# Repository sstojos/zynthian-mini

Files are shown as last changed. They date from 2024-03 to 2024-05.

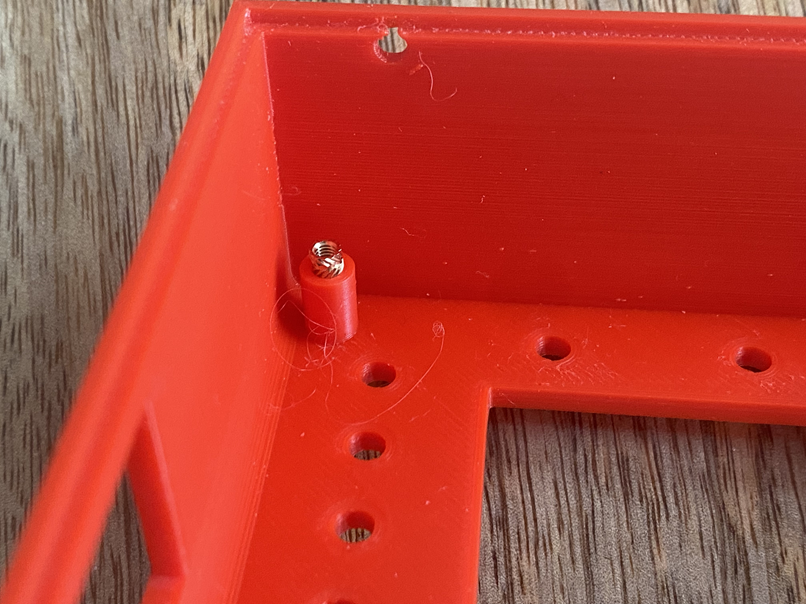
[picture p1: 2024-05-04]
resources/assembly-1.png

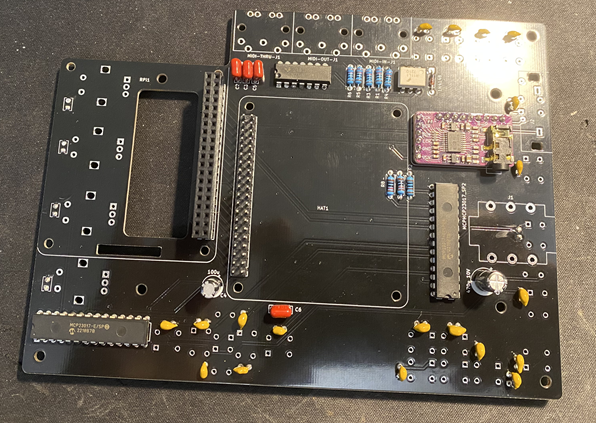
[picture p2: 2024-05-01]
resources/soldering-step-6.png

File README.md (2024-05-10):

THIS IS AN OLD reposiotry OF ZYNTHIAN MINI !!!

Zyntian MINI is not any more maintained here.

Zynthian MINI is now merged to zynthian-hw repository. You can find latest verison of zynthian mini inside [forked repository of zynthian-hw](https://github.com/sstojos/zynthian-hw) inside MINI_V2 folder.

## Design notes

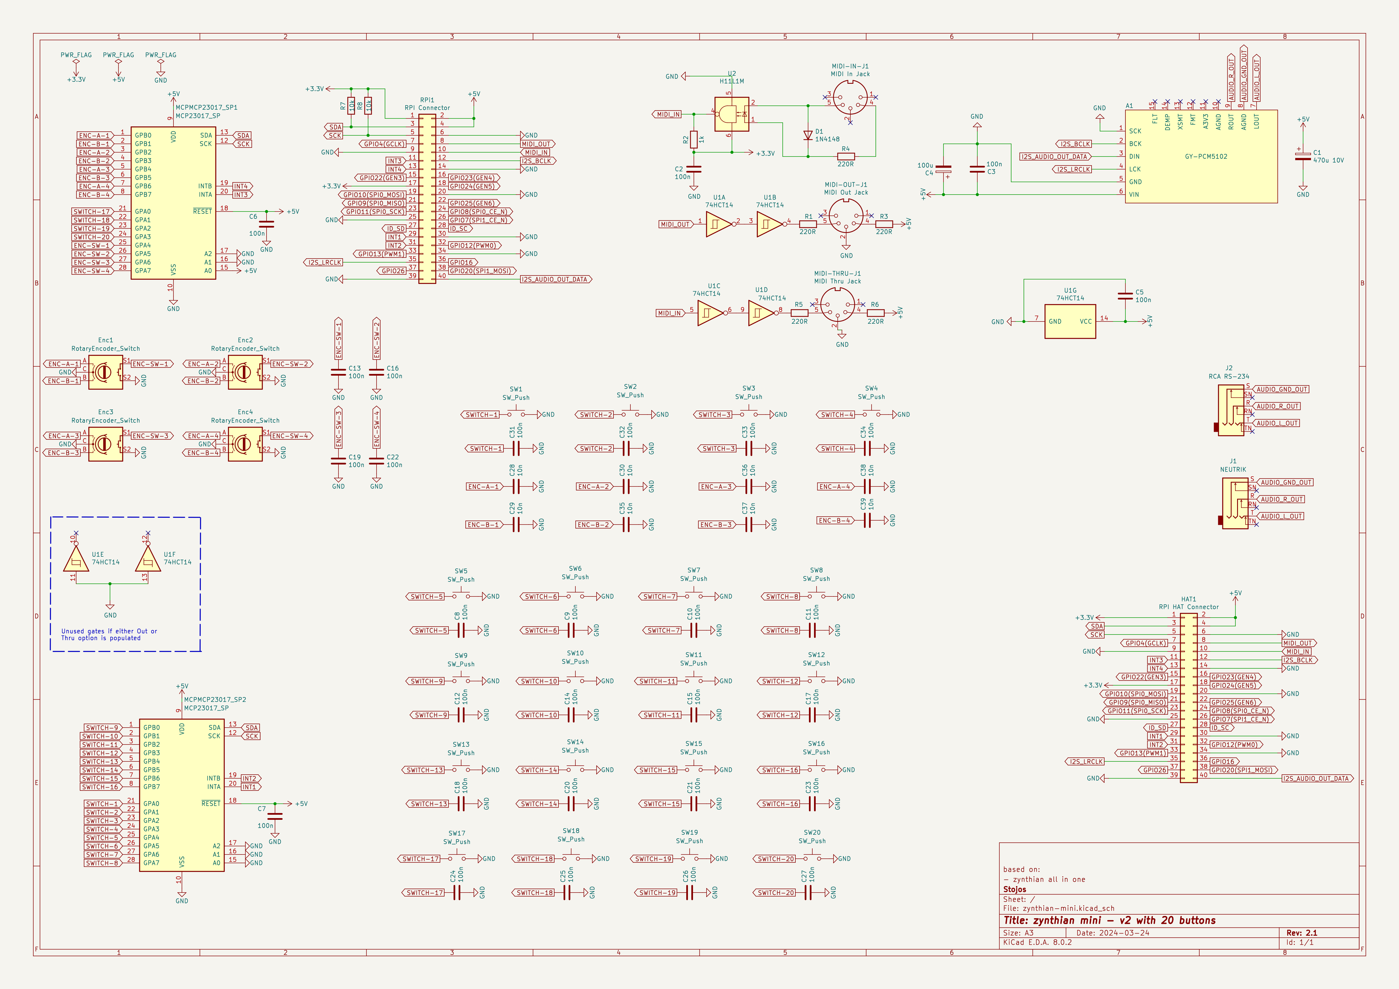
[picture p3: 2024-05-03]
resources/schematics.png

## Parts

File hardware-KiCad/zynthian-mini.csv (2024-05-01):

Id | Designator | Footprint | Quantity | Designation | Supplier and ref
1 | RPi1 | raspberry pi 4 HAT | 1 | RPI Connector
2 | C1 | CP_Radial_D8.0mm_P3.50mm | 1 | 470u 10V
3 | C2,C3,C5,C6,C7 | C_Rect_L7.0mm_W2.0mm_P5.00mm | 5 | 100n
4 | C4 | CP_Radial_D6.3mm_P2.50mm | 1 | 100u
5 | D1 | D_DO-35_SOD27_P7.62mm_Horizontal | 1 | 1N4148
6 | MIDI-OUT-J1 | MultiDIN5 | 1 | MIDI Out Jack
7 | MIDI-IN-J1 | MultiDIN5 | 1 | MIDI In Jack
8 | R1,R3,R5,R4,R6 | R_Axial_DIN0207_L6.3mm_D2.5mm_P7.62mm_Horizontal | 5 | 220R
9 | R2 | R_Axial_DIN0207_L6.3mm_D2.5mm_P7.62mm_Horizontal | 1 | 1k
10 | U2 | DIP-6_W7.62mm | 1 | H11L1M
11 | U1 | DIP-14_W7.62mm | 1 | 74HCT14
12 | A1 | GY-PCM5102 | 1 | GY-PCM5102
13 | C30,C29,C35,C37,C38,C28,C39,C36 | C_Rect_L4.0mm_W2.5mm_P2.50mm | 8 | 10n
14 | J2 | RCA RS-234 | 1 | RCA RS-234
15 | HAT1 | raspberry pi 4 | 1 | RPI HAT Connector
16 | R8,R7 | R_Axial_DIN0207_L6.3mm_D2.5mm_P7.62mm_Horizontal | 2 | 10k
17 | MCPMCP23017_SP2,MCPMCP23017_SP1 | DIP-28_W7.62mm | 2 | MCP23017_SP
18 | C22,C16,C19,C13,C23,C20,C9,C26,C27,C32,C8,C18,C21,C34,C33,C17,C25,C11,C24,C31,C12,C15,C10,C14 | C_Rect_L4.0mm_W2.5mm_P2.50mm | 24 | 100n
19 | MIDI-THRU-J1 | MultiDIN5 | 1 | MIDI Thru Jack
20 | screen | aliexpress 5 inch screen | 1 | aliexpress 5 inch screen
21 | J1 | Jack_6.35mm_Neutrik_NMJ6HFD2_Horizontal | 1 | NEUTRIK
22 | SW14,SW9,SW16,SW20,SW6,SW10,SW8,SW2,SW17,SW4,SW12,SW19,SW5,SW1,SW13,SW18,SW15,SW7,SW11,SW3 | push-button | 20 | SW_Push
23 | Enc2,Enc4,Enc1,Enc3 | RotaryEncoder_Alps_EC12E-Switch_Vertical_H20mm | 4 | RotaryEncoder_Switch
24 | G*** | Zynthian Logo Mask | 1 | MINI v2

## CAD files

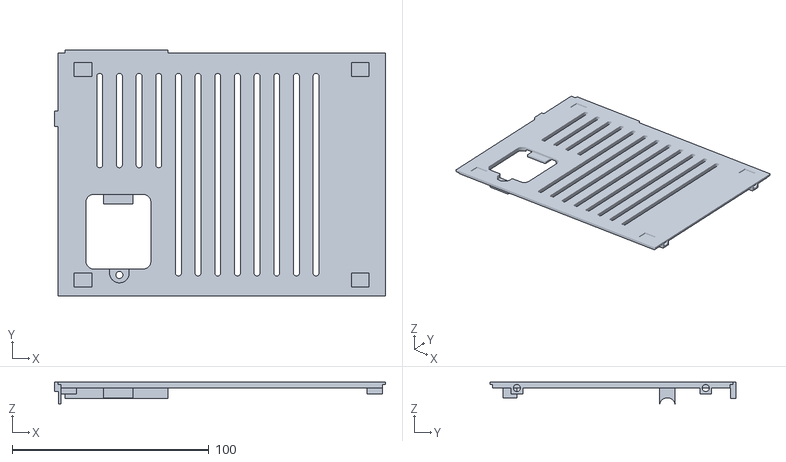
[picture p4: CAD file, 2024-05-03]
CAD/bottom.stl
168.3 x 125.3 x 11.1

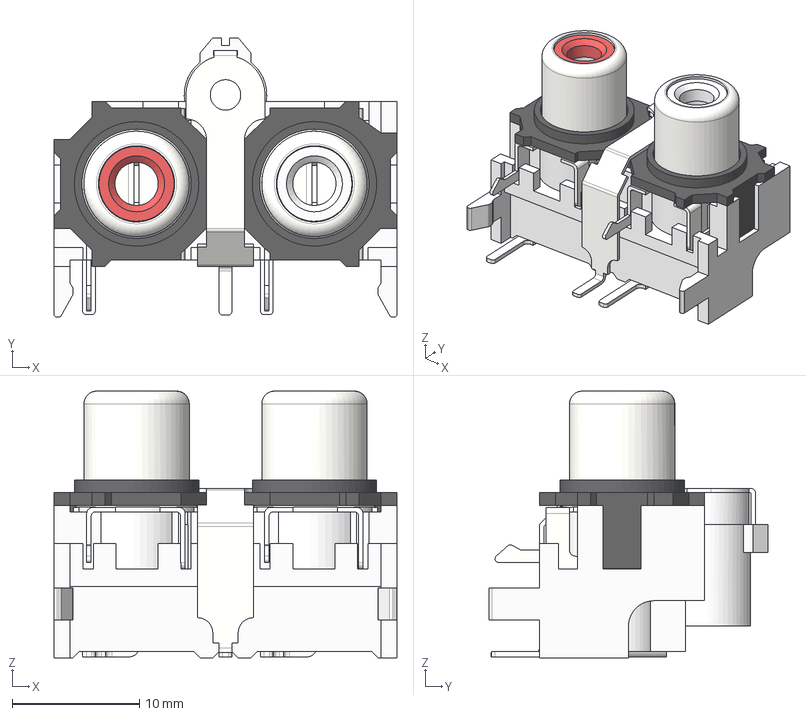
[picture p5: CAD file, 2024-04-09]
hardware-KiCad/RS-234.stp
27.0 x 22.0 x 21.0 mm

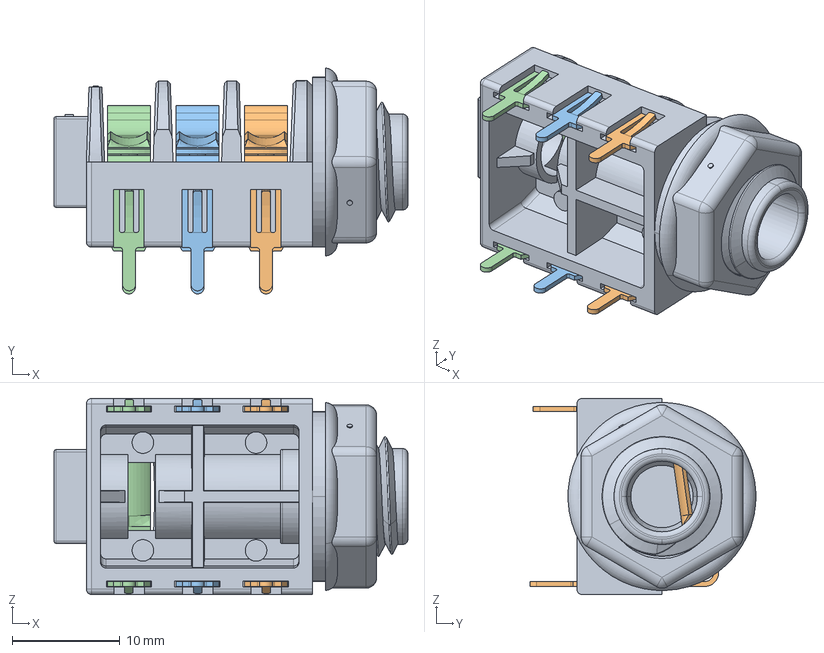
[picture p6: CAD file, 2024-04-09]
hardware-KiCad/nmj6hfd2.stp
32.9 x 21.0 x 18.2 mm

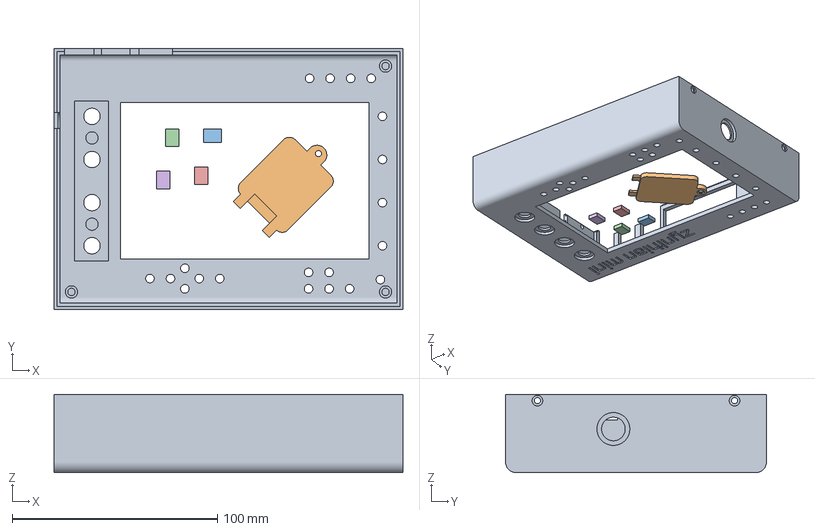
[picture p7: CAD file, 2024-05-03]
CAD/orca-slicer-project-01.3mf
170.0 x 127.0 x 38.0 mm
top.stl
sd-card-door.stl
leg.stl x 4

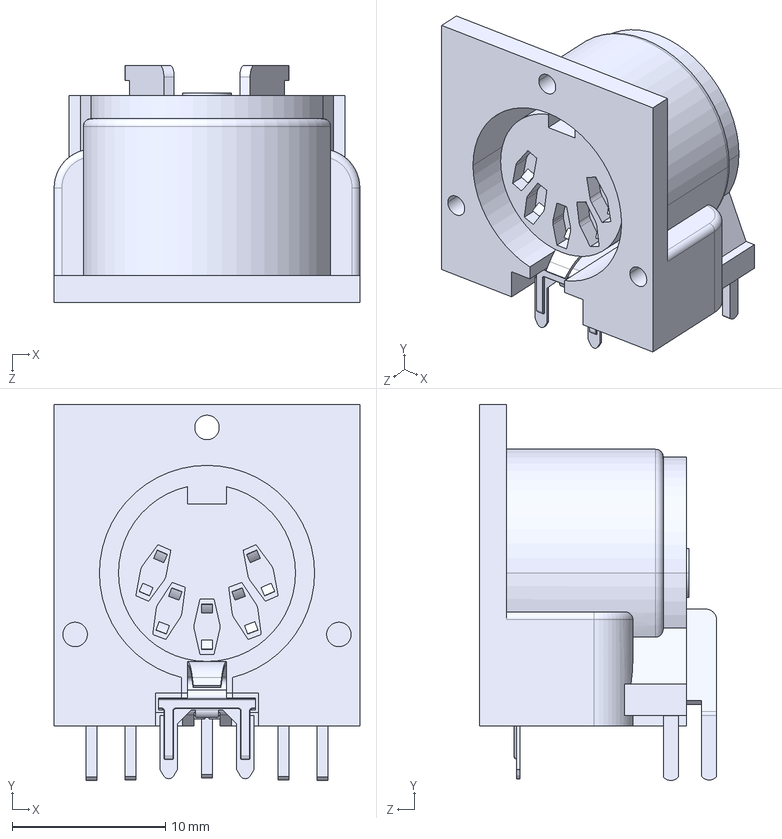
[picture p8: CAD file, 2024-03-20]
hardware-KiCad/midi-connector.step
20.0 x 24.5 x 15.5 mm

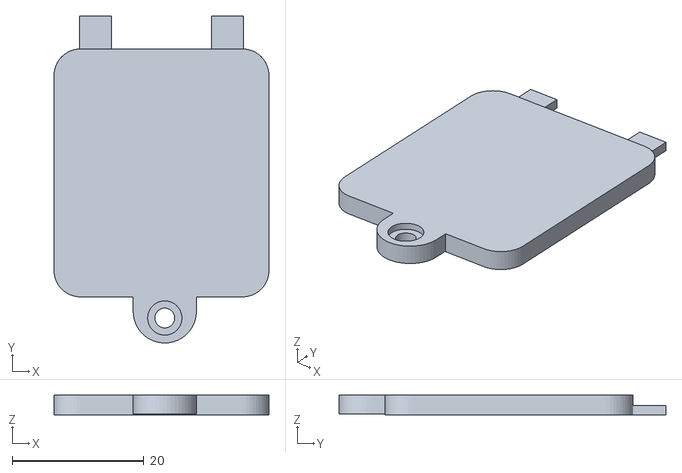
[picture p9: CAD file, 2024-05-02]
CAD/sd-card-door.stl
32.6 x 49.6 x 3.00

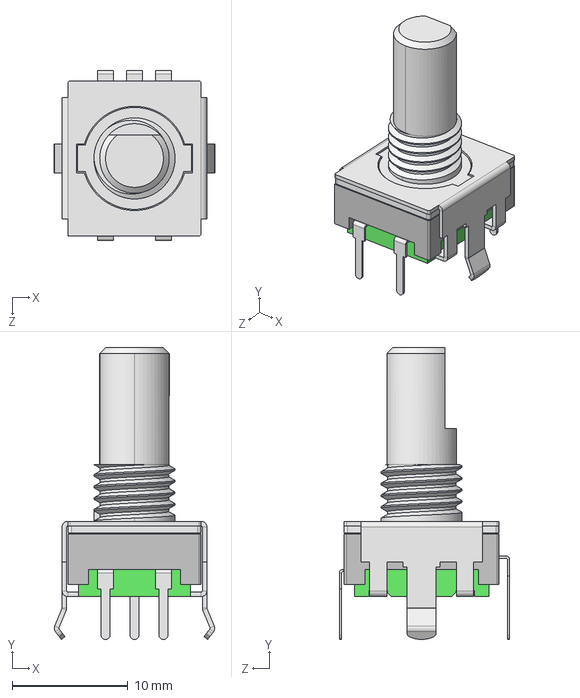
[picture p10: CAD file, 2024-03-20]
hardware-KiCad/rotary-encoder.step
13.9 x 25.2 x 14.7 mm

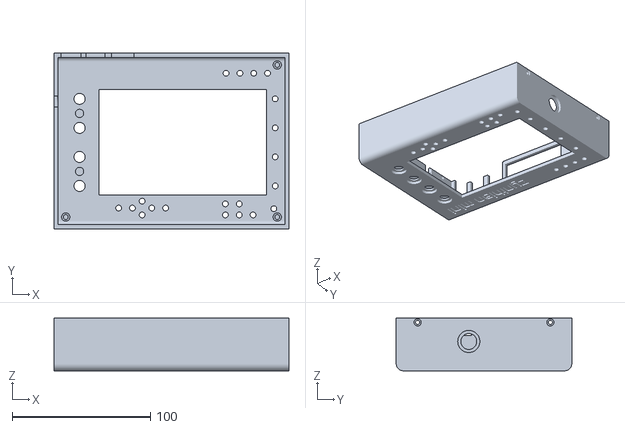
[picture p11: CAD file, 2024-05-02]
CAD/top.stl
170.0 x 127.0 x 38.0

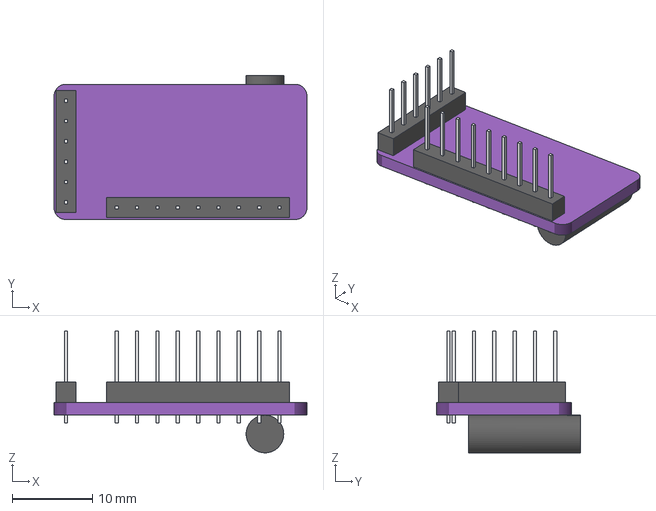
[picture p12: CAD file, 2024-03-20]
hardware-KiCad/PCM5102-I2S.step
31.6 x 18.0 x 15.2 mm

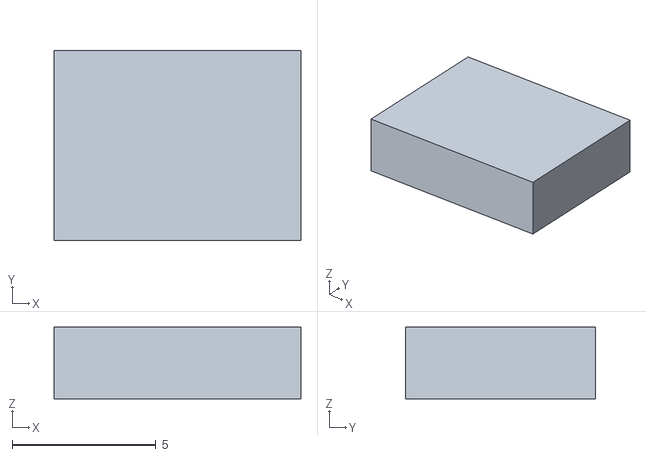
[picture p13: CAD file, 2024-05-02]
CAD/leg.stl
8.60 x 6.60 x 2.50

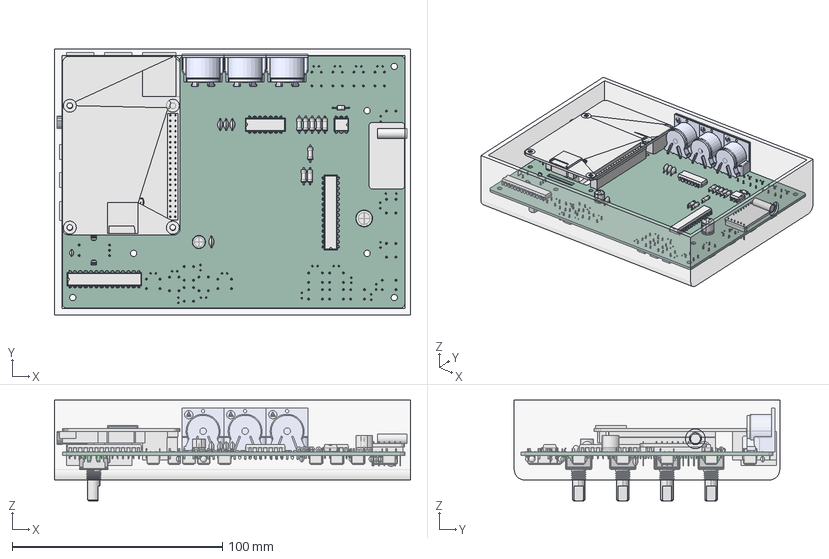
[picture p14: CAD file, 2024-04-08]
CAD/case-freecad.FCStd
169.4 x 126.4 x 48.0 mm
Top Case
Raspberry Pi 4 B
Raspberry Pi 4 B001
Raspberry Pi 4 B002
Raspberry Pi 4 B003
Raspberry Pi 4 B004
Raspberry Pi 4 B005
Raspberry Pi 4 B006
Raspberry Pi 4 B007
Raspberry Pi 4 B008
Raspberry Pi 4 B009
Raspberry Pi 4 B010
Raspberry Pi 4 B011
Raspberry Pi 4 B012
Raspberry Pi 4 B013
Raspberry Pi 4 B014
Raspberry Pi 4 B015
Raspberry Pi 4 B016
Raspberry Pi 4 B017
Raspberry Pi 4 B018
Raspberry Pi 4 B019
Raspberry Pi 4 B020
PinSocket_2x20_P254mm_Vertical
CP_Radial_D80mm_P350mm
C_Disc_D50mm_W25mm_P500mm
C_Disc_D50mm_W25mm_P500mm001
CP_Radial_D63mm_P250mm
C_Disc_D50mm_W25mm_P500mm002
D_DO-35_SOD27_P7.62mm_Horizontal
D_DO-35_SOD27_P7.62mm_Horizontal001
57PC5F
57PC5F001
R_Axial_DIN0207_L63mm_D25mm_P762mm_Horizontal
R_Axial_DIN0207_L63mm_D25mm_P762mm_Horizontal001
R_Axial_DIN0207_L63mm_D25mm_P762mm_Horizontal002
R_Axial_DIN0207_L63mm_D25mm_P762mm_Horizontal003
DIP-6_W7.62mm
DIP-14_W7.62mm
R_Axial_DIN0207_L63mm_D25mm_P762mm_Horizontal004
R_Axial_DIN0207_L63mm_D25mm_P762mm_Horizontal005
DIP-28_W7.62mm
C_Disc_D30mm_W20mm_P250mm
C_Disc_D30mm_W20mm_P250mm001
R_Axial_DIN0207_L63mm_D25mm_P762mm_Horizontal006
R_Axial_DIN0207_L63mm_D25mm_P762mm_Horizontal007
57PC5F002
DIP-28_W7.62mm002
C_Disc_D50mm_W25mm_P500mm003
C_Disc_D30mm_W20mm_P250mm002
C_Disc_D30mm_W20mm_P250mm003
SW_PUSH_6mm
C_Disc_D30mm_W20mm_P250mm004
C_Disc_D50mm_W25mm_P500mm004
C_Disc_D30mm_W20mm_P250mm005
SW_PUSH_6mm002
C_Disc_D30mm_W20mm_P250mm006
C_Disc_D30mm_W20mm_P250mm007
PEC11R-4215F-S0024
PEC11R-4215F-S0025
PEC11R-4215F-S0026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

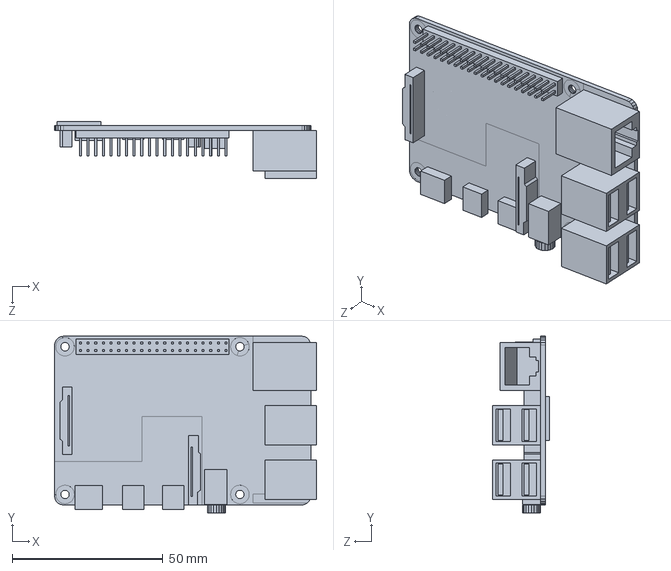
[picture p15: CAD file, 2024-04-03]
CAD/Raspberry_Pi_4_B.STEP
86.9 x 58.6 x 19.0 mm

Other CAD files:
CAD/orca-slicer-project-02.3mf

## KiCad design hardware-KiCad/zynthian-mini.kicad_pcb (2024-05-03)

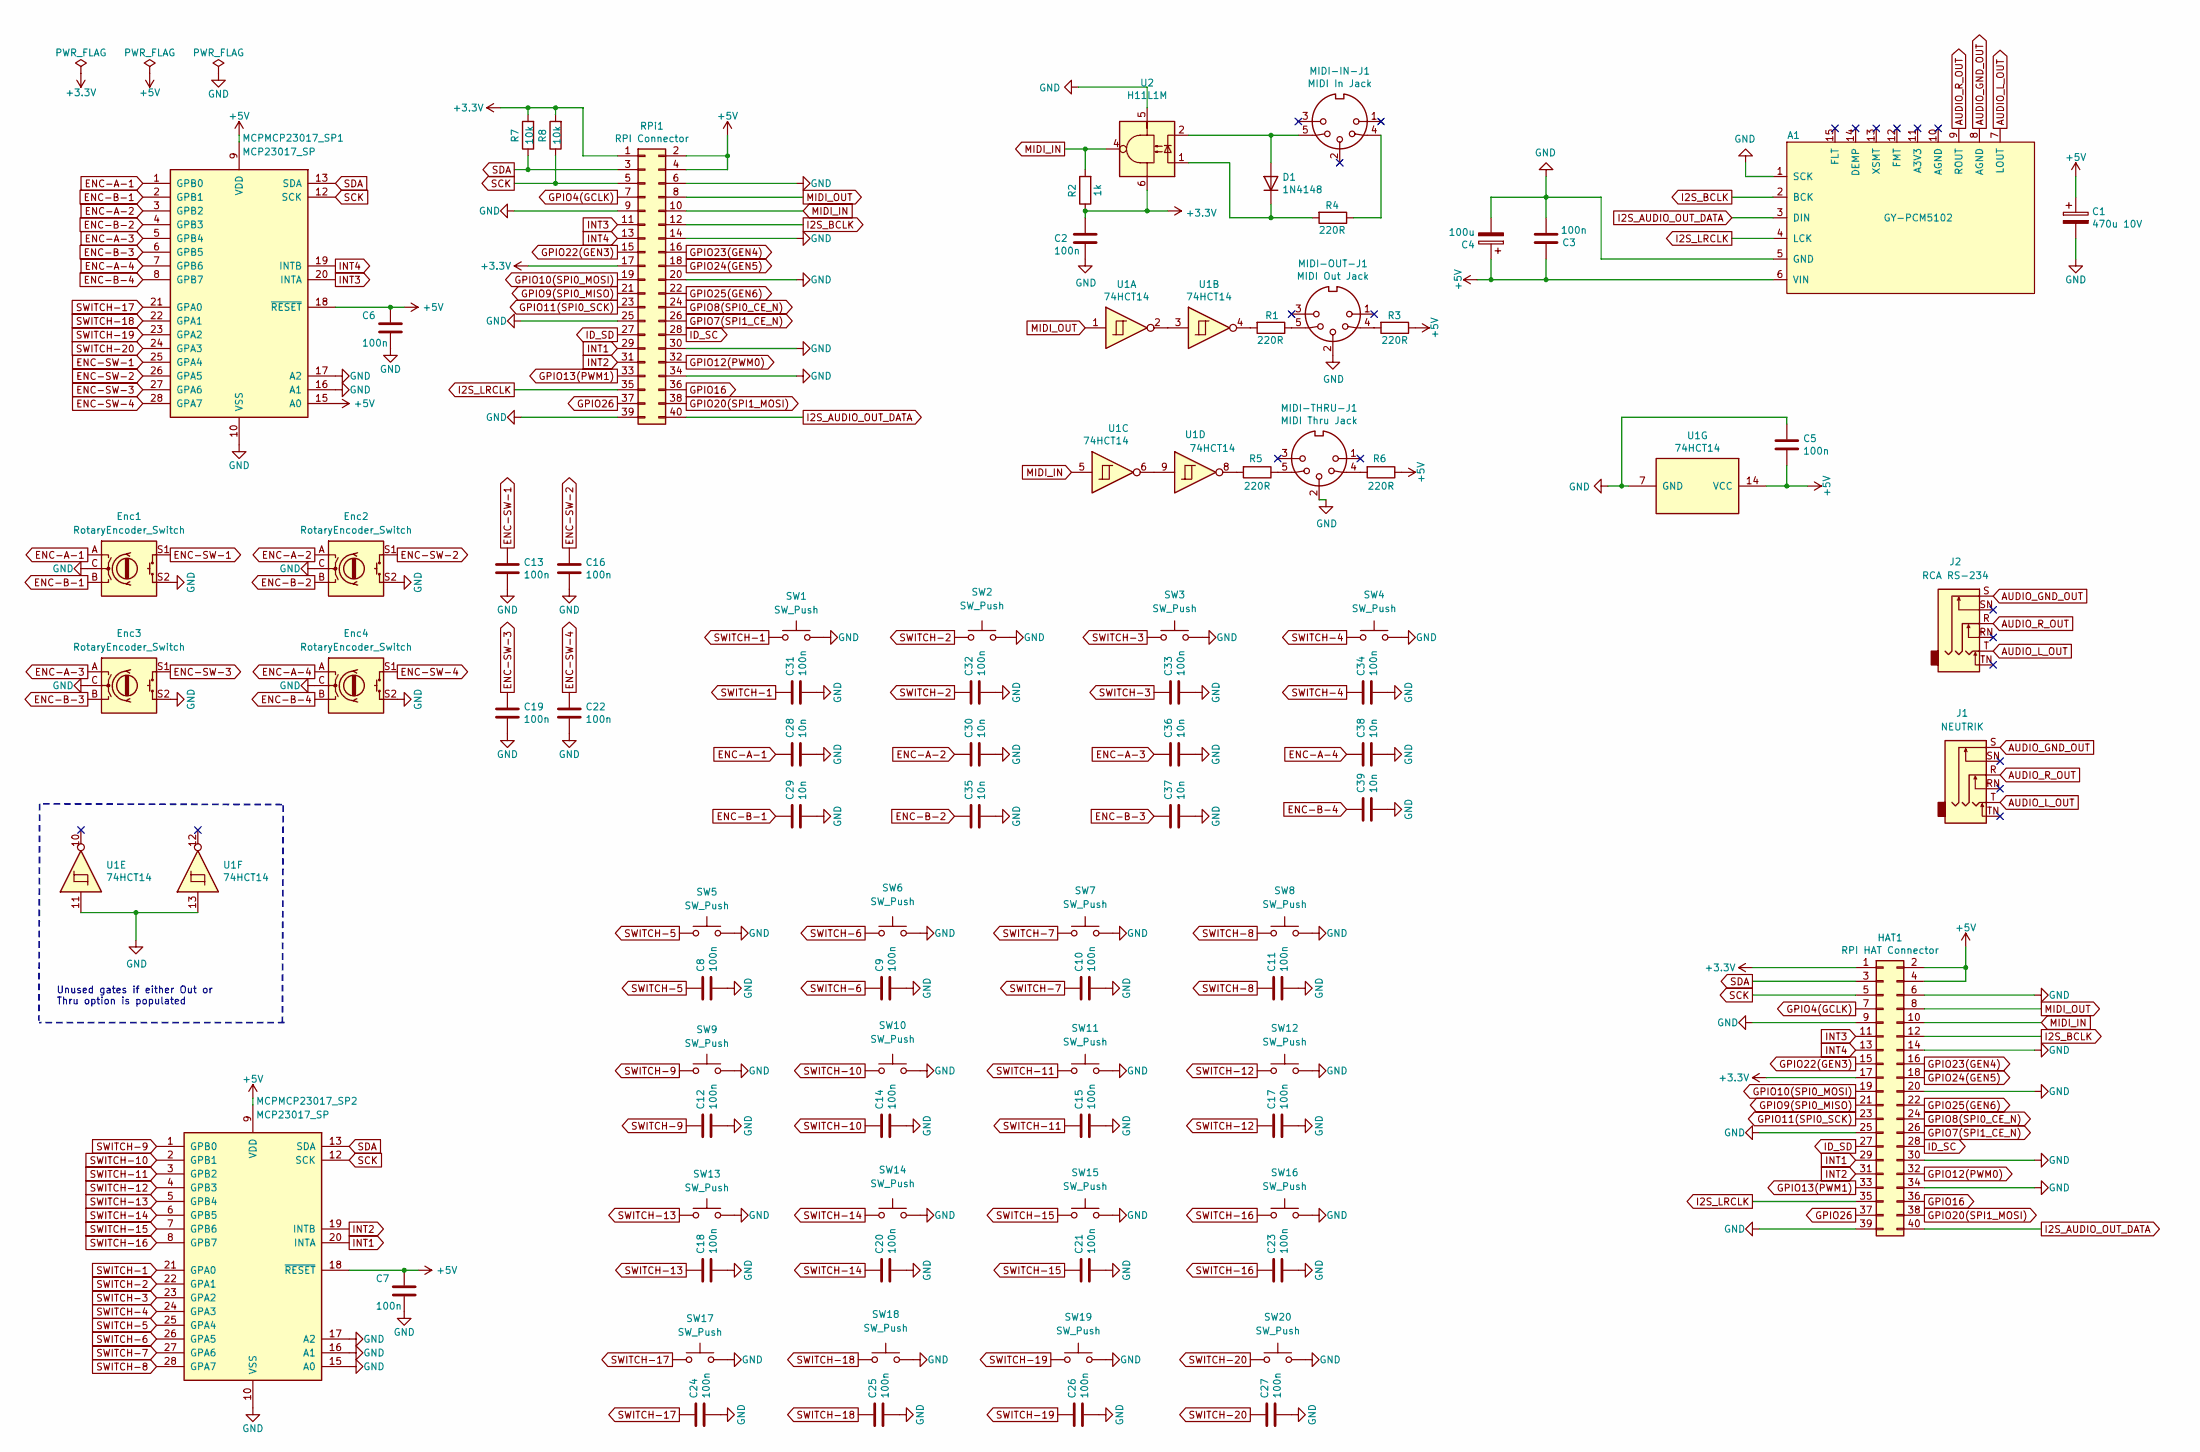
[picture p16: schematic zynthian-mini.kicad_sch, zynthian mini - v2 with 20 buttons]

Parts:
A1: GY-PCM5102
C1: 470u 10V; CP_Radial_D8.0mm_P3.50mm
C2, C3, C5, C6, C7: 100n; C_Rect_L7.0mm_W2.0mm_P5.00mm
C4: 100u; CP_Radial_D6.3mm_P2.50mm
C8, C9, C10, C11, C12, C13, C14, C15, C16, C17, C18, C19, C20, C21, C22, C23, C24, C25, C26, C27, C31, C32, C33, C34: 100n; C_Rect_L4.0mm_W2.5mm_P2.50mm
C28, C29, C30, C35, C36, C37, C38, C39: 10n; C_Rect_L4.0mm_W2.5mm_P2.50mm
D1: 1N4148; D_DO-35_SOD27_P7.62mm_Horizontal
Enc1, Enc2, Enc3, Enc4: RotaryEncoder_Switch; RotaryEncoder_Alps_EC12E-Switch_Vertical_H20mm
HAT1: RPI HAT Connector; raspberry pi 4
J1: NEUTRIK; Jack_6.35mm_Neutrik_NMJ6HFD2_Horizontal
J2: RCA RS-234
MCPMCP23017_SP1, MCPMCP23017_SP2: MCP23017_SP; DIP-28_W7.62mm
MIDI-IN-J1: MIDI In Jack; MultiDIN5
MIDI-OUT-J1: MIDI Out Jack; MultiDIN5
MIDI-THRU-J1: MIDI Thru Jack; MultiDIN5
R1, R3, R4, R5, R6: 220R; R_Axial_DIN0207_L6.3mm_D2.5mm_P7.62mm_Horizontal
R2: 1k; R_Axial_DIN0207_L6.3mm_D2.5mm_P7.62mm_Horizontal
R7, R8: 10k; R_Axial_DIN0207_L6.3mm_D2.5mm_P7.62mm_Horizontal
RPi1: RPI Connector; raspberry pi 4 HAT
SW1, SW2, SW3, SW4, SW5, SW6, SW7, SW8, SW9, SW10, SW11, SW12, SW13, SW14, SW15, SW16, SW17, SW18, SW19, SW20: SW_Push; push-button
U1: 74HCT14; DIP-14_W7.62mm
U2: H11L1M; DIP-6_W7.62mm

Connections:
AUDIO_GND_OUT: A1.8 (AGND), J1.S, J2.S
AUDIO_L_OUT: A1.7 (LOUT), J1.T, J2.T
AUDIO_R_OUT: A1.9 (ROUT), J1.R, J2.R
ENC-A-1: C28.1, Enc1.A, MCPMCP23017_SP1.1 (GPB0)
ENC-A-2: C30.1, Enc2.A, MCPMCP23017_SP1.3 (GPB2)
ENC-A-3: C36.1, Enc3.A, MCPMCP23017_SP1.5 (GPB4)
ENC-A-4: C38.1, Enc4.A, MCPMCP23017_SP1.7 (GPB6)
ENC-B-1: C29.1, Enc1.B, MCPMCP23017_SP1.2 (GPB1)
ENC-B-2: C35.1, Enc2.B, MCPMCP23017_SP1.4 (GPB3)
ENC-B-3: C37.1, Enc3.B, MCPMCP23017_SP1.6 (GPB5)
ENC-B-4: C39.1, Enc4.B, MCPMCP23017_SP1.8 (GPB7)
ENC-SW-1: C13.1, Enc1.S1, MCPMCP23017_SP1.25 (GPA4)
ENC-SW-2: C16.1, Enc2.S1, MCPMCP23017_SP1.26 (GPA5)
ENC-SW-3: C19.1, Enc3.S1, MCPMCP23017_SP1.27 (GPA6)
ENC-SW-4: C22.1, Enc4.S1, MCPMCP23017_SP1.28 (GPA7)
GPIO4(GCLK): HAT1.7, RPi1.7
GPIO7(SPI1_CE_N): HAT1.26, RPi1.26
GPIO8(SPI0_CE_N): HAT1.24, RPi1.24
GPIO9(SPI0_MISO): HAT1.21, RPi1.21
GPIO10(SPI0_MOSI): HAT1.19, RPi1.19
GPIO11(SPI0_SCK): HAT1.23, RPi1.23
GPIO12(PWM0): HAT1.32, RPi1.32
GPIO13(PWM1): HAT1.33, RPi1.33
GPIO16: HAT1.36, RPi1.36
GPIO20(SPI1_MOSI): HAT1.38, RPi1.38
GPIO22(GEN3): HAT1.15, RPi1.15
GPIO23(GEN4): HAT1.16, RPi1.16
GPIO24(GEN5): HAT1.18, RPi1.18
GPIO25(GEN6): HAT1.22, RPi1.22
GPIO26: HAT1.37, RPi1.37
I2S_AUDIO_OUT_DATA: A1.3 (DIN), HAT1.40, RPi1.40
I2S_BCLK: A1.2 (BCK), HAT1.12, RPi1.12
I2S_LRCLK: A1.4 (LCK), HAT1.35, RPi1.35
ID_SC: HAT1.28, RPi1.28
ID_SD: HAT1.27, RPi1.27
INT1: HAT1.29, MCPMCP23017_SP2.20 (INTA), RPi1.29
INT2: HAT1.31, MCPMCP23017_SP2.19 (INTB), RPi1.31
INT3: HAT1.11, MCPMCP23017_SP1.20 (INTA), RPi1.11
INT4: HAT1.13, MCPMCP23017_SP1.19 (INTB), RPi1.13
MIDI_IN: HAT1.10, R2.2, RPi1.10, U1.5, U2.4
MIDI_OUT: HAT1.8, RPi1.8, U1.1
unnamed: D1.2 (A), MIDI-IN-J1.5, U2.2
unnamed: D1.1 (K), R4.2, U2.1
unnamed: MIDI-IN-J1.4, R4.1
unnamed: MIDI-OUT-J1.4, R3.2
unnamed: MIDI-OUT-J1.5, R1.1
unnamed: MIDI-THRU-J1.4, R6.2
unnamed: MIDI-THRU-J1.5, R5.1
unnamed: R1.2, U1.4
unnamed: R5.2, U1.8
unnamed: U1.2, U1.3
unnamed: U1.6, U1.9
SCK: HAT1.5, MCPMCP23017_SP1.12 (SCK), MCPMCP23017_SP2.12 (SCK), R8.1, RPi1.5
SDA: HAT1.3, MCPMCP23017_SP1.13 (SDA), MCPMCP23017_SP2.13 (SDA), R7.1, RPi1.3
SWITCH-1: C31.1, MCPMCP23017_SP2.21 (GPA0), SW1.1
SWITCH-2: C32.1, MCPMCP23017_SP2.22 (GPA1), SW2.1
SWITCH-3: C33.1, MCPMCP23017_SP2.23 (GPA2), SW3.1
SWITCH-4: C34.1, MCPMCP23017_SP2.24 (GPA3), SW4.1
SWITCH-5: C8.1, MCPMCP23017_SP2.25 (GPA4), SW5.1
SWITCH-6: C9.1, MCPMCP23017_SP2.26 (GPA5), SW6.1
SWITCH-7: C10.1, MCPMCP23017_SP2.27 (GPA6), SW7.1
SWITCH-8: C11.1, MCPMCP23017_SP2.28 (GPA7), SW8.1
SWITCH-9: C12.1, MCPMCP23017_SP2.1 (GPB0), SW9.1
SWITCH-10: C14.1, MCPMCP23017_SP2.2 (GPB1), SW10.1
SWITCH-11: C15.1, MCPMCP23017_SP2.3 (GPB2), SW11.1
SWITCH-12: C17.1, MCPMCP23017_SP2.4 (GPB3), SW12.1
SWITCH-13: C18.1, MCPMCP23017_SP2.5 (GPB4), SW13.1
SWITCH-14: C20.1, MCPMCP23017_SP2.6 (GPB5), SW14.1
SWITCH-15: C21.1, MCPMCP23017_SP2.7 (GPB6), SW15.1
SWITCH-16: C23.1, MCPMCP23017_SP2.8 (GPB7), SW16.1
SWITCH-17: C24.1, MCPMCP23017_SP1.21 (GPA0), SW17.1
SWITCH-18: C25.1, MCPMCP23017_SP1.22 (GPA1), SW18.1
SWITCH-19: C26.1, MCPMCP23017_SP1.23 (GPA2), SW19.1
SWITCH-20: C27.1, MCPMCP23017_SP1.24 (GPA3), SW20.1

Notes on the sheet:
Unused gates if either Out or Thru option is populated

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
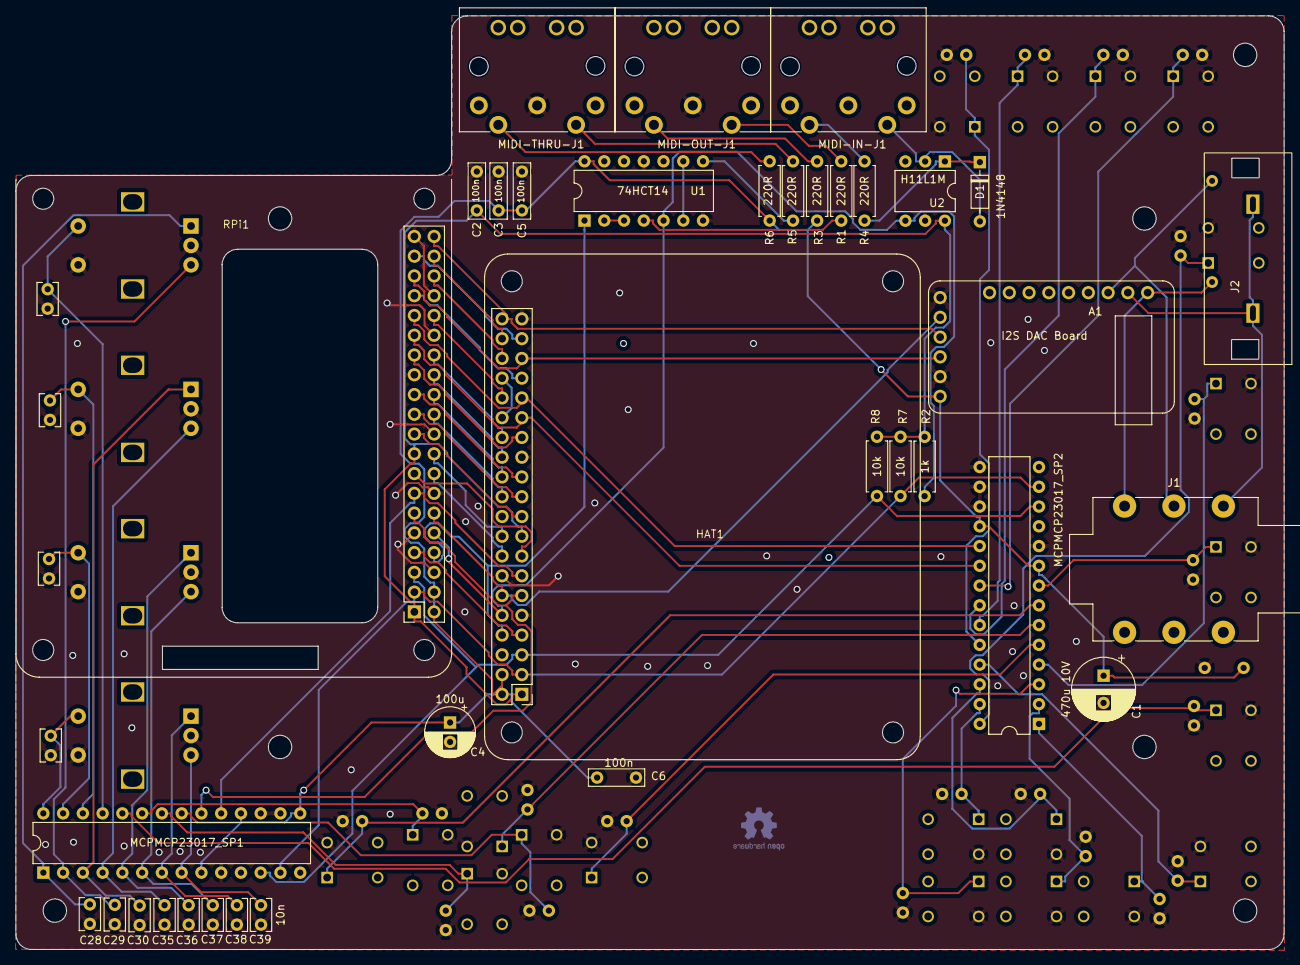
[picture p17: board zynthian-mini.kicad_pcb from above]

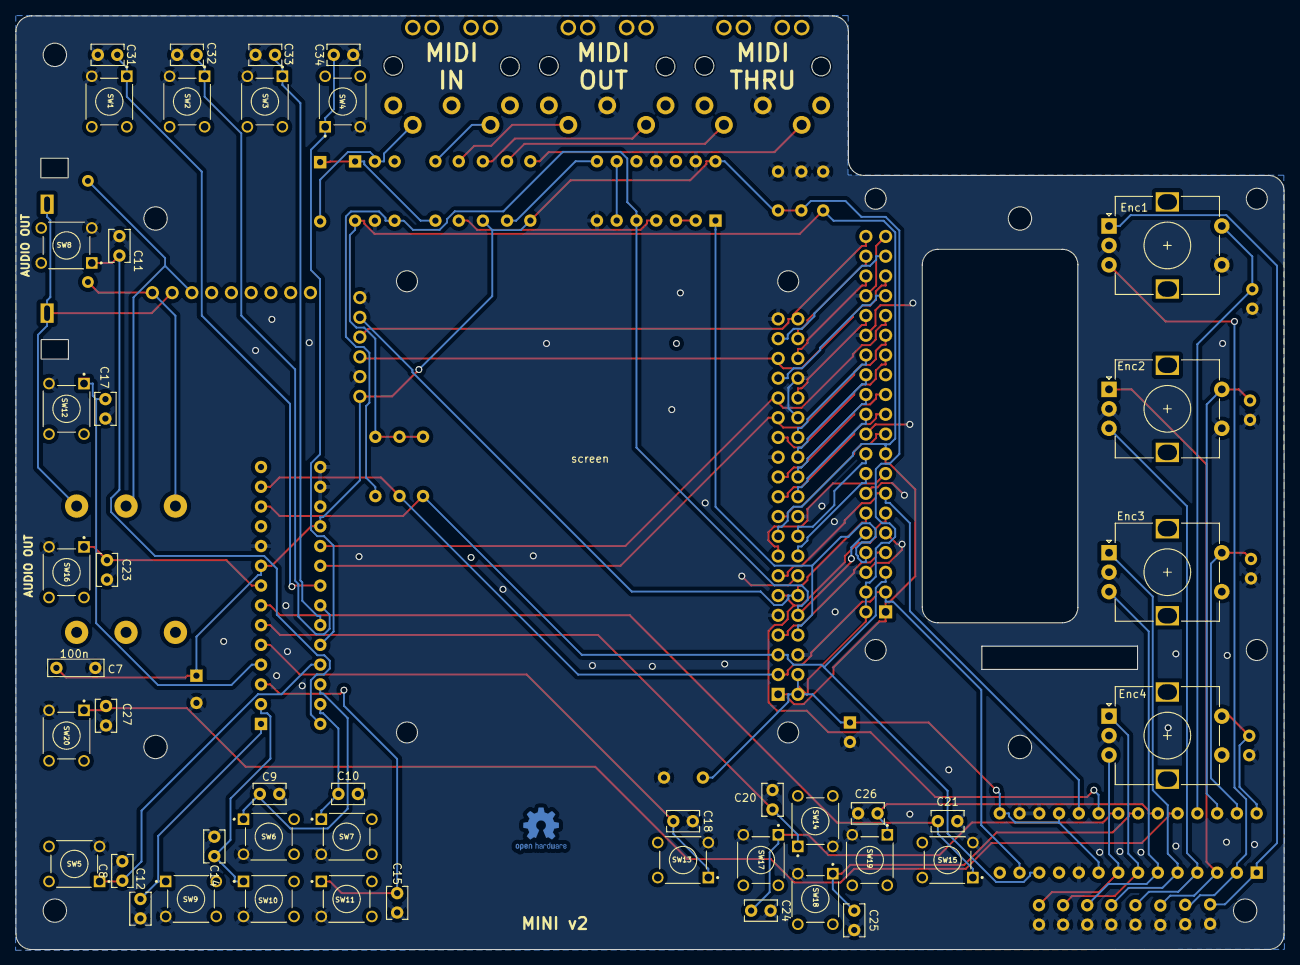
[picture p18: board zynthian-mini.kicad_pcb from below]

Board: 2 copper layers, 163.0 x 120.0 mm, 85 parts (45 on the bottom side), 77 nets.

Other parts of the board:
screen: aliexpress 5 inch screen

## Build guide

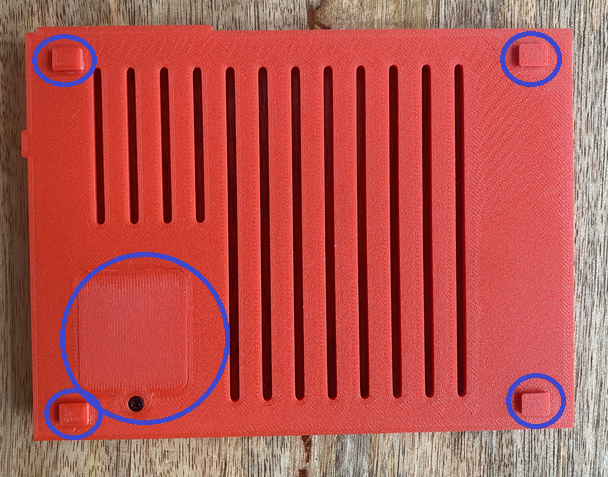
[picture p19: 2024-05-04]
resources/assembly-14.png

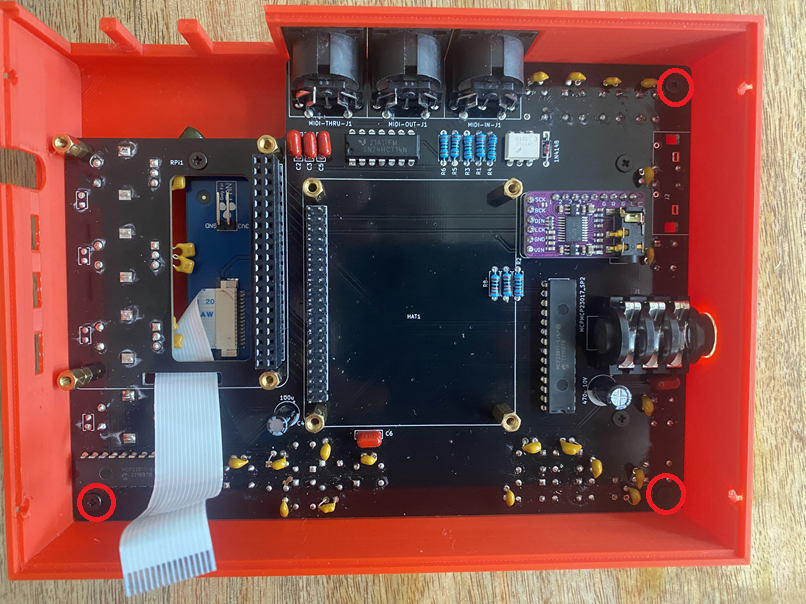
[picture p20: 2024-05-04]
resources/assembly-9.png

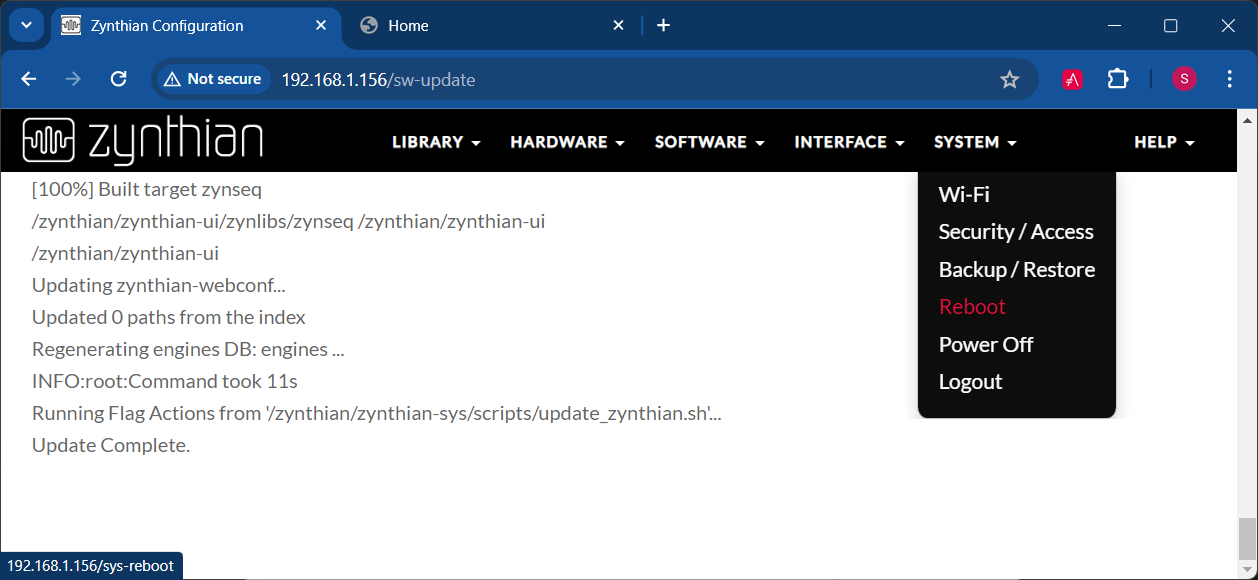
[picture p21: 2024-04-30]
resources/config-step-03.png

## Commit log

2024-03-20 first release
    [zynthian-mini.kicad_pcb]
2024-03-24 migration to KiCad 8.0
    [zynthian-mini.kicad_pcb, zynthian-mini.kicad_sch]
2024-03-31 second release
    [zynthian-mini.kicad_pcb]
2024-04-02 Revert "second release"
    This reverts commit bd4749c021c126e3d20c8e6cac66855f5c73ca6a.
    [zynthian-mini.kicad_pcb]
2024-04-02 removed kicad lock file
2024-04-02 Reapply "second release"
    This reverts commit ecf339a646dc757298e7c83805a64127a07718a0.
    [zynthian-mini.kicad_pcb]
2024-04-03 PCB board edge chnage
    [zynthian-mini.kicad_pcb]
2024-04-03 first button layout try
    [zynthian-mini.kicad_pcb, zynthian-mini.kicad_sch]
2024-04-03 work on PCB switches and CAD
    [Raspberry_Pi_4_B.STEP, case-freecad-Top Case.stl, case-freecad.FCStd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]
2024-04-04 first usable v2-20-buttons version
    [case-freecad.FCStd, zynthian-mini.kicad_pcb]
2024-04-06 making space for rpi4
    [zynthian-mini.kicad_pcb]
2024-04-08 first workable solution for v2 20 pins
    [case-freecad.FCStd, zynthian-mini.kicad_pcb, zynthian-mini.kicad_sch]
2024-04-09 added RCA, Neutrik and HAT connector
    [RS-234.stp, case.FCStd, nmj6hfd2.stp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]
2024-04-09 added PCB back with rpi image
2024-04-09 added posts for PCB inside the case
    [case-freecad-Top Case.3mf, case-freecad-Top Case.stl]
2024-04-23 v2 assembling photos and latest 3d design
    [case-freecad-Top Case.stl]
2024-04-26 CAD design final
    [bottom.stl, case-freecad-Top Case.3mf, case-freecad-Top Case.stl]
2024-04-30 added encoder de bouncing caps
    [zynthian-mini.kicad_pcb, zynthian-mini.kicad_sch]
2024-04-30 assembly photo updates
2024-05-01 assembling images sorted
    [zynthian-mini.csv]
2024-05-01 another assembling images additions / changes
2024-05-01 finished case design and exported all parts in stl
    [leg.stl, sd-card-door.stl, top.stl]
2024-05-02 final case adjustments
    [bottom.stl, leg.stl, sd-card-door.stl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]
2024-05-03 small changes to silkscreen component info
    [zynthian-mini.kicad_pcb]
2024-05-03 added orcaslicer project and fixed bottom part openings
    [bottom.stl, orca-slicer-project-01.3mf, orca-slicer-project-02.3mf]
2024-05-04 assembling photos
